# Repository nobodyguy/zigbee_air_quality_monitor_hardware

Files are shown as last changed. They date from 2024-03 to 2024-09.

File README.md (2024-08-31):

# Zigbee air quality monitor board
Opensource HA compatible air quality monitor with CO2, temperature and humidity measurements.

* KiCAD 8.X required 
* Includes nrf52840 module
* Includes SCD40/SCD41 module

## Firmware
https://github.com/nobodyguy/zigbee_air_quality_monitor_firmware

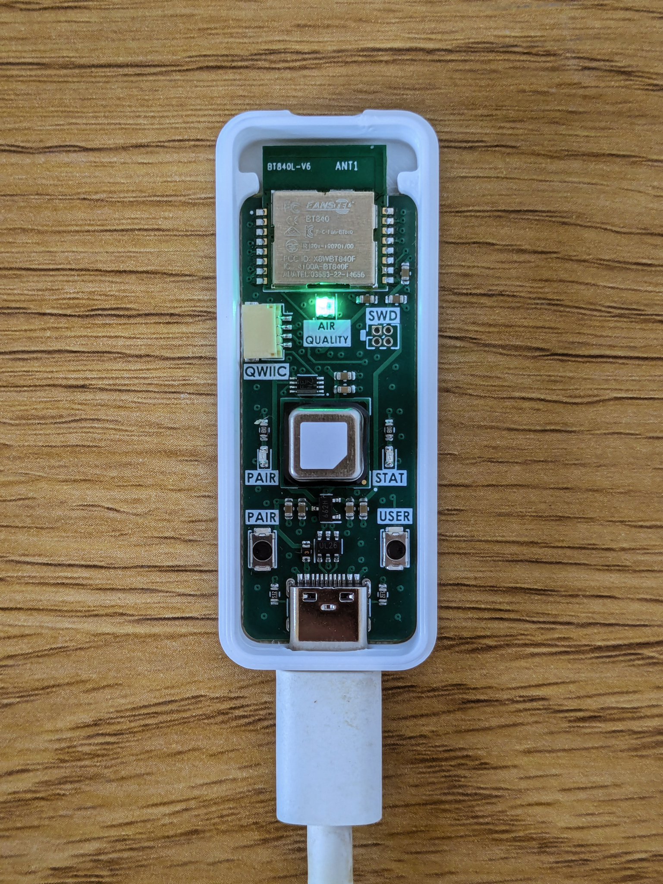
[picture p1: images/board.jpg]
Board


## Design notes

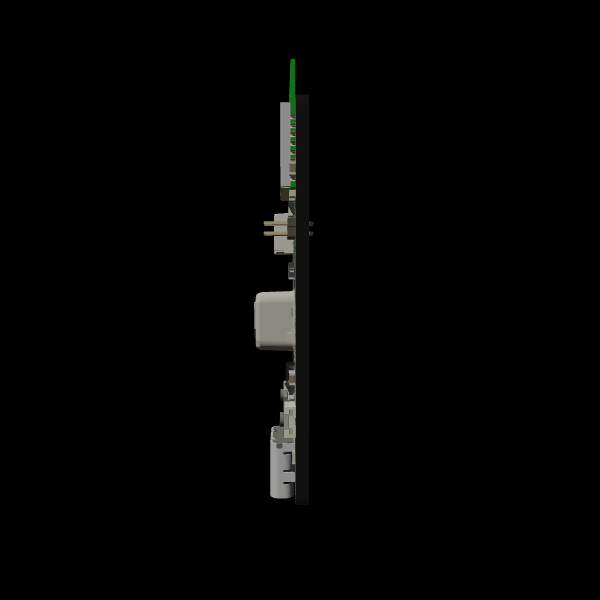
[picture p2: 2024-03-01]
images/pcb_animation.gif

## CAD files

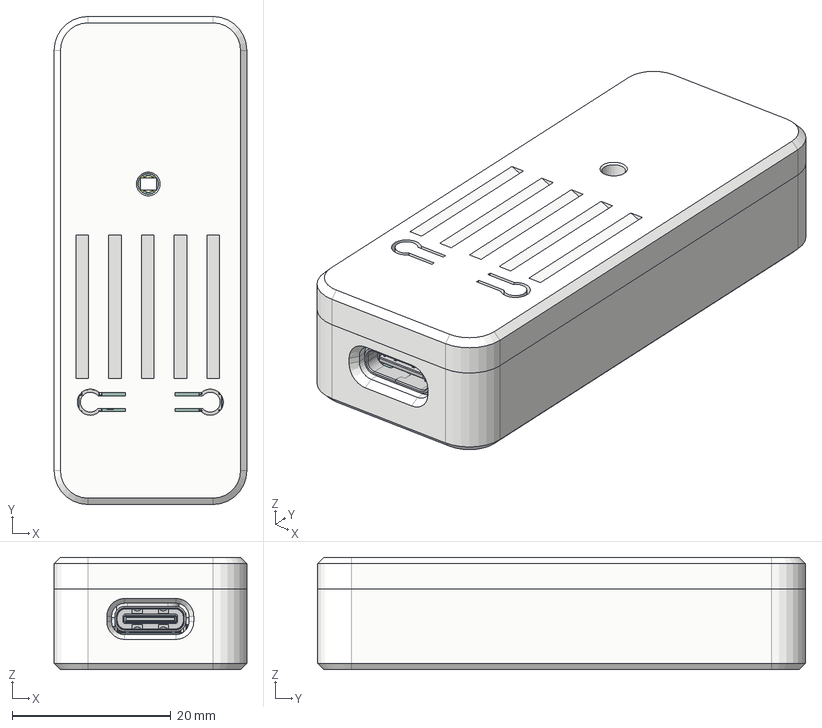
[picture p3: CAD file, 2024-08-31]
enclosure/zigbee_air_quality_monitor_case_v69.step
24.2 x 61.4 x 14.1 mm
R_0603_1608Metric x 4
C_0603_1608Metric x 11
zigbee_air_quality_monitor 1.5.1
149693-00_SCD4x_Datasheet
SOT_23_6
L_0603_1608Metric
SKRKAEE020 x 2
SOT_23
Fuse_0603_1608Metric
TYPE-C-31-M-12
LED_0603_1608Metric x 2
VSSOP_8_23x2mm_P05mm
PinHeader_2x02_P127mm_Vertical
WS2812B-2020
BT840
zigbee_air_quality_monitor PCB
TopCase
BottomCase

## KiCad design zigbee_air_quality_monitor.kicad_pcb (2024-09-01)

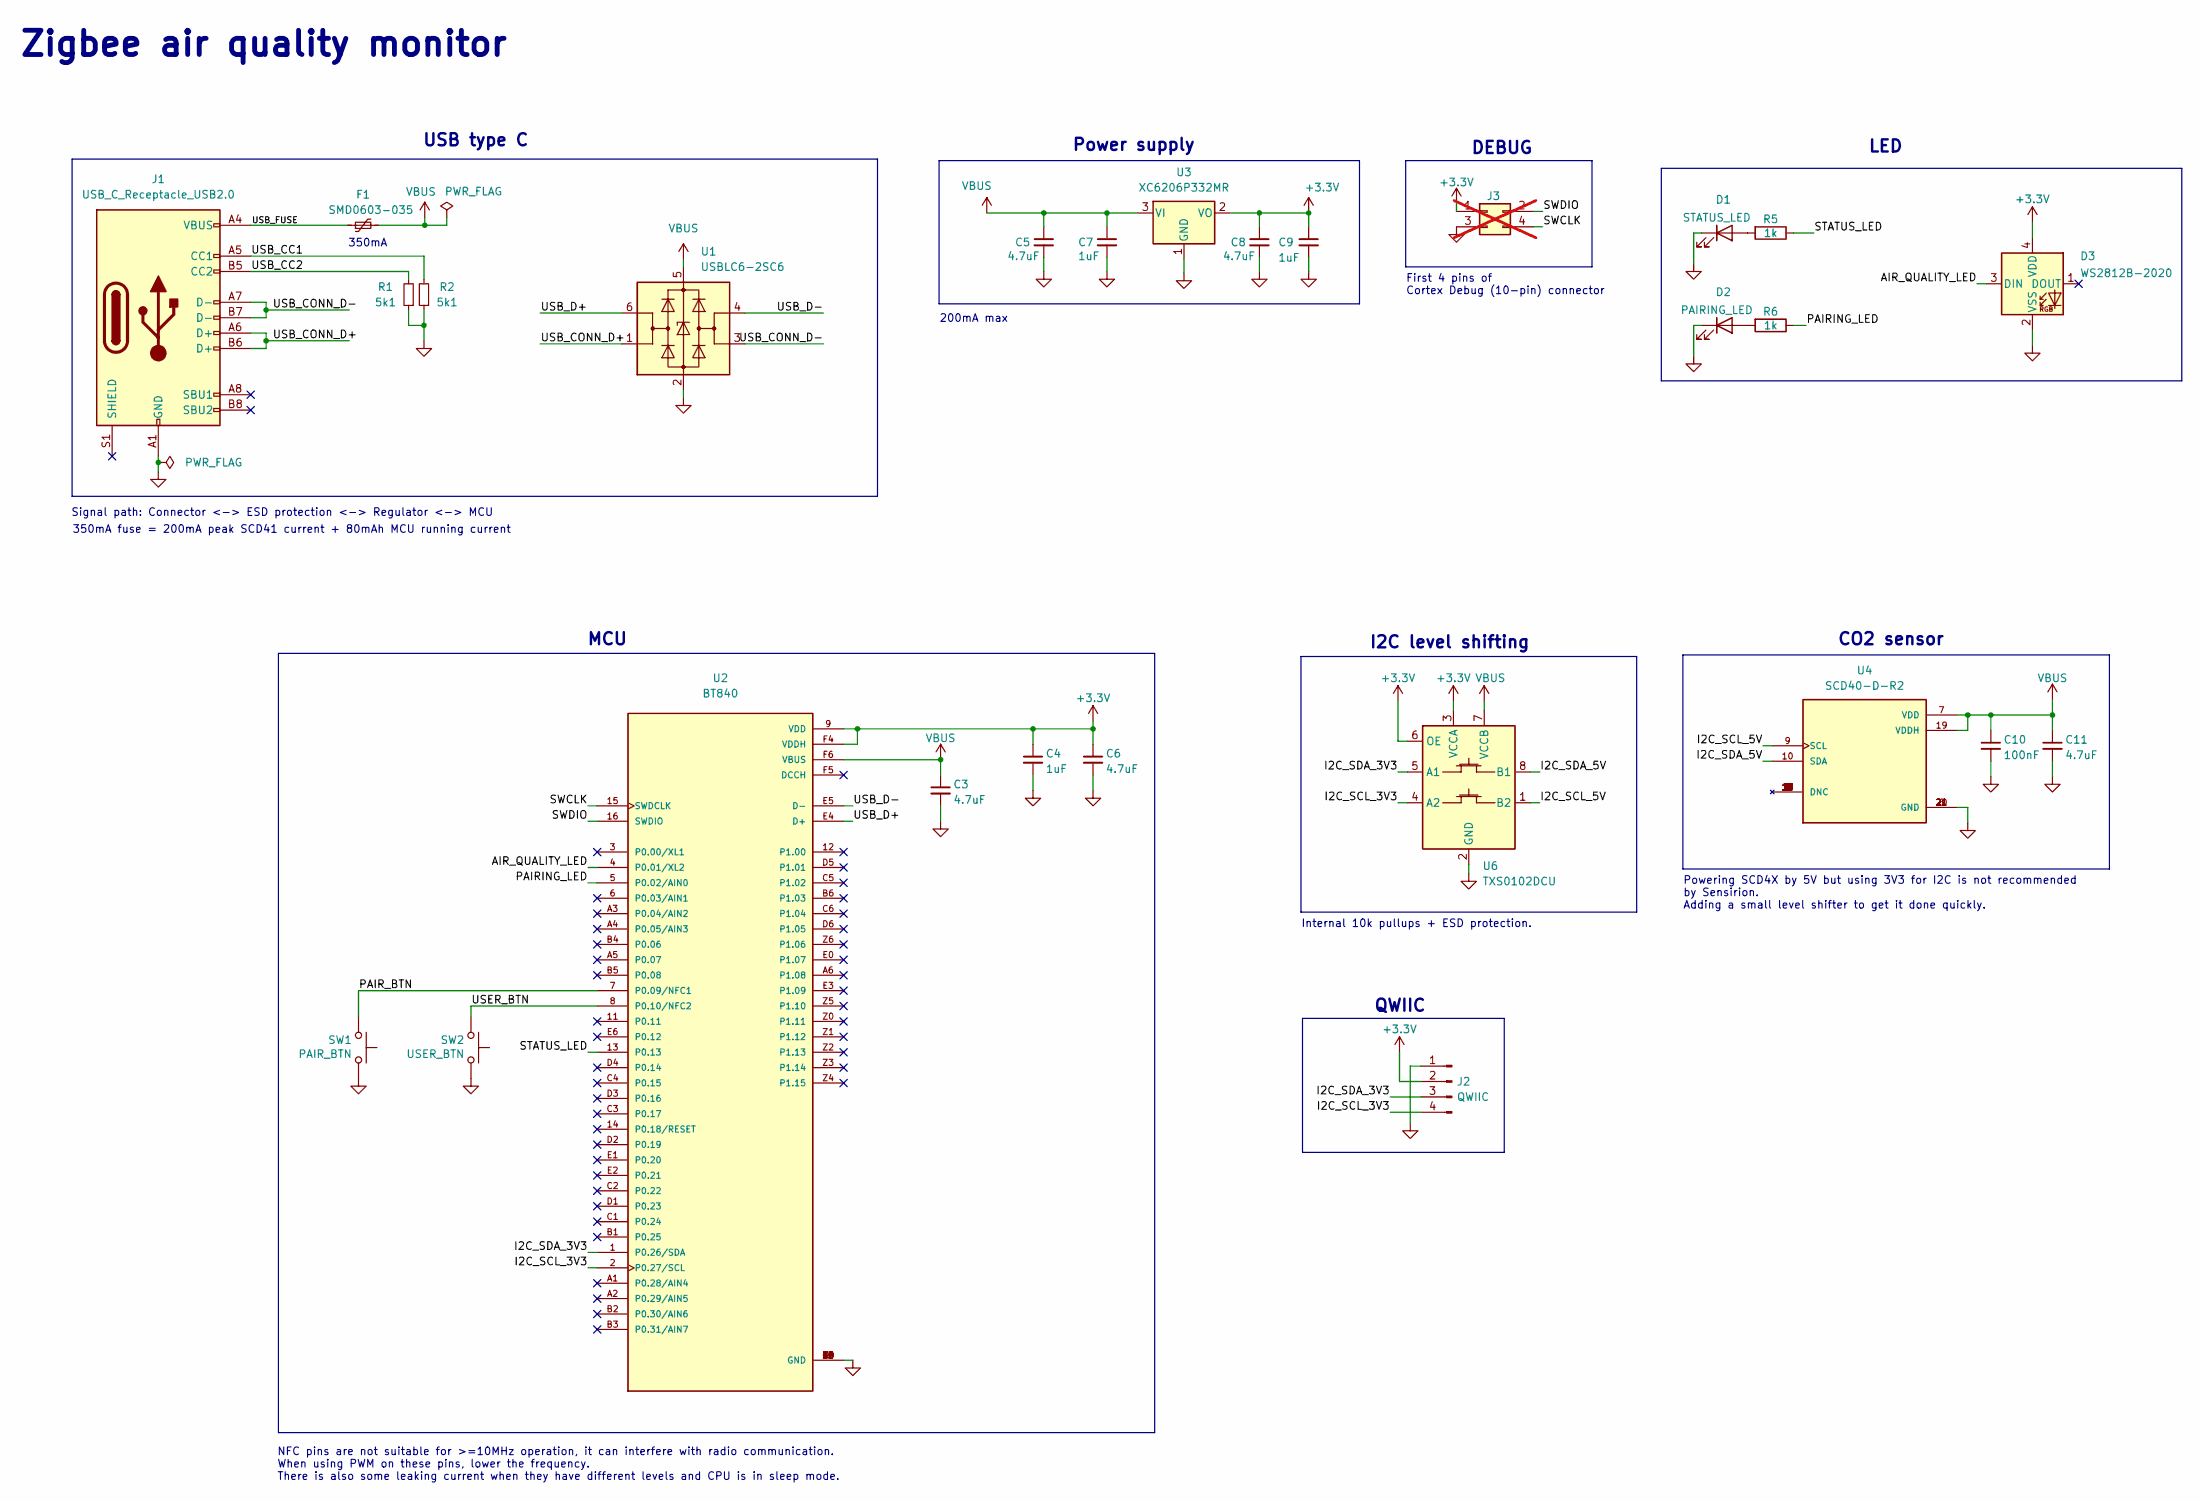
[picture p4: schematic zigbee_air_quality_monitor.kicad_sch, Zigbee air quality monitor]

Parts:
C3, C5, C6, C8, C11: 4.7uF; C_0603_1608Metric; LCSC Part C19666
C4, C7, C9: 1uF; C_0603_1608Metric; LCSC Part C15849
C10: 100nF; C_0603_1608Metric; LCSC Part C14663
D1: STATUS_LED; LED_0603_1608Metric; LCSC Part C965804
D2: PAIRING_LED; LED_0603_1608Metric; LCSC Part C965807
D3: WS2812B-2020; LED_WS2812B_PLCC4_5.0x5.0mm_P3.2mm; LCSC Part C965555
F1: SMD0603-035; Fuse_0603_1608Metric; LCSC Part C910818
J1: USB_C_Receptacle_USB2.0; USB_C_Receptacle_HRO_TYPE-C-31-M-12; LCSC Part C165948
J2: QWIIC; JST_SH_SM04B-SRSS-TB_1x04-1MP_P1.00mm_Horizontal; LCSC Part C9900058894
J3: Conn_02x02_Odd_Even; PinHeader_2x02_P1.27mm_Vertical; not fitted
R1, R2: 5k1; R_0603_1608Metric; LCSC Part C23186
R5, R6: 1k; R_0603_1608Metric; LCSC Part C21190
SW1: PAIR_BTN; SW_Push_SPST_NO_Alps_SKRK; LCSC Part C115357
SW2: USER_BTN; SW_Push_SPST_NO_Alps_SKRK; LCSC Part C115357
U1: USBLC6-2SC6; SOT-23-6; LCSC Part C2827654
U2: BT840; LCSC Part C5182373
U3: XC6206P332MR; SOT-23; LCSC Part C5446
U4: SCD40-D-R2; XDCR_SCD41-D-R2; PARTREV 1.2; LCSC Part C3659421
U6: TXS0102DCU; VSSOP-8_2.3x2mm_P0.5mm; LCSC Part C53434

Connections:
+3.3V: C4.1, C6.1, C8.1, C9.1, D3.4 (VDD), J2.2, J3.1, U2.9 (VDD), U2.F4 (VDDH), U3.2 (VO), U6.3 (VCCA), U6.6 (OE)
/AIR_QUALITY_LED: D3.3 (DIN), U2.4 (P0.01/XL2)
/I2C_SCL_3V3: J2.4, U2.2 (P0.27/SCL), U6.4 (A2)
/I2C_SCL_5V: U4.9 (SCL), U6.1 (B2)
/I2C_SDA_3V3: J2.3, U2.1 (P0.26/SDA), U6.5 (A1)
/I2C_SDA_5V: U4.10 (SDA), U6.8 (B1)
/PAIRING_LED: R6.1, U2.5 (P0.02/AIN0)
/PAIR_BTN: SW1.1, U2.7 (P0.09/NFC1)
/STATUS_LED: R5.1, U2.13 (P0.13)
/SWCLK: J3.4, U2.15 (SWDCLK)
/SWDIO: J3.2, U2.16 (SWDIO)
/USB_CC1: J1.A5 (CC1), R2.2
/USB_CC2: J1.B5 (CC2), R1.2
/USB_CONN_D+: J1.A6 (D+), J1.B6 (D+), U1.1 (I/O1)
/USB_CONN_D-: J1.A7 (D-), J1.B7 (D-), U1.3 (I/O2)
/USB_D+: U1.6 (I/O1), U2.E4 (D+)
/USB_D-: U1.4 (I/O2), U2.E5 (D-)
/USB_FUSE: F1.1, J1.A4 (VBUS), J1.A9 (VBUS), J1.B4 (VBUS), J1.B9 (VBUS)
/USER_BTN: SW2.1, U2.8 (P0.10/NFC2)
GND: C3.2, C4.2, C5.2, C6.2, C7.2, C8.2, C9.2, C10.2, C11.2, D1.1 (K), D2.1 (K), D3.2 (VSS), J1.A1 (GND), J1.A12 (GND), J1.B1 (GND), J1.B12 (GND), J2.1, J3.3, R1.1, R2.1, SW1.2, SW2.2, U1.2 (GND), U2.10 (GND), U2.A0 (GND), U2.B0 (GND), U2.C0 (GND), U2.D0 (GND), U2.F0 (GND), U2.F1 (GND), U2.F2 (GND), U2.F3 (GND), U3.1 (GND), U4.6 (GND), U4.20 (GND), U4.21 (GND), U6.2 (GND)
unnamed: D1.2 (A), R5.2
unnamed: D2.2 (A), R6.2
VBUS: C3.1, C5.1, C7.1, C10.1, C11.1, F1.2, U1.5 (VBUS), U2.F6 (VBUS), U3.3 (VI), U4.7 (VDD), U4.19 (VDDH), U6.7 (VCCB)

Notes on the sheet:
Internal 10k pullups + ESD protection.
DEBUG
LED
MCU
350mA
Power supply
200mA max
NFC pins are not suitable for >=10MHz operation, it can interfere with radio communication. When using PWM on these pins, lower the frequency. There is also some leaking current when they have different levels and CPU is in sleep mode.
Powering SCD4X by 5V but using 3V3 for I2C is not recommended by Sensirion. Adding a small level shifter to get it done quickly.
USB type C
CO2 sensor
First 4 pins of Cortex Debug (10-pin) connector
Signal path: Connector <-> ESD protection <-> Regulator <-> MCU
I2C level shifting
350mA fuse = 200mA peak SCD41 current + 80mAh MCU running current
Zigbee air quality monitor
QWIIC

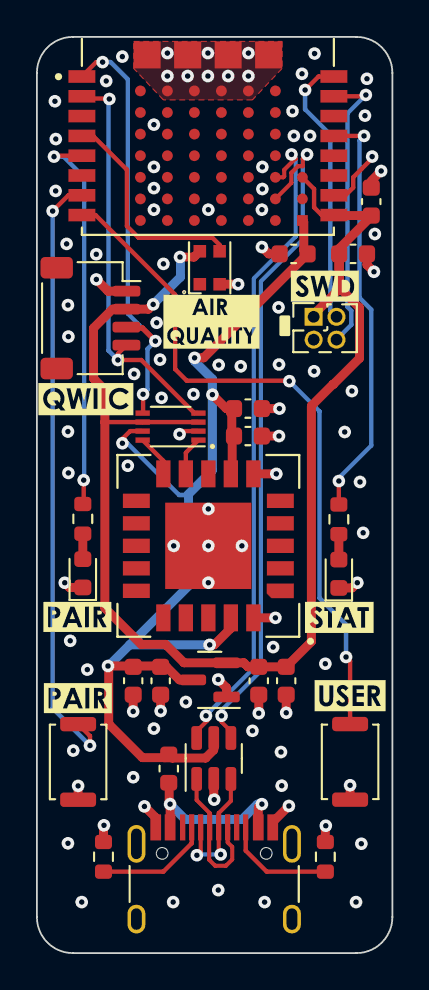
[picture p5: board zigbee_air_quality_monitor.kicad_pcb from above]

Board: 4 copper layers, 19.8 x 50.9 mm, 35 parts (1 on the bottom side), 23 nets.

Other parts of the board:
G1: LOGO
kibuzzard-63D9ACF8: G***; kibuzzard-63D9ACF8
kibuzzard-63D64B8B, kibuzzard-63D64B8B#2: G***; kibuzzard-63D64B8B
kibuzzard-63D64B66: G***; kibuzzard-63D64B66
kibuzzard-63D6450F: G***; kibuzzard-63D6450F
kibuzzard-63D64107: G***; kibuzzard-63D64107
kibuzzard-63D64589: G***; footprint

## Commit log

2023-01-20 Zigbee module, PN and jtag schematics
    [zigbee_air_quality_monitor.kicad_pcb, zigbee_air_quality_monitor.kicad_sch]
2023-01-29 Finished schematics, added 3D models
    [zigbee_air_quality_monitor.kicad_pcb, zigbee_air_quality_monitor.kicad_sch]
2023-02-04 Rough part placement
    [zigbee_air_quality_monitor.kicad_pcb, zigbee_air_quality_monitor.kicad_sch]
2024-02-25 Routing WIP
    [zigbee_air_quality_monitor.kicad_pcb, zigbee_air_quality_monitor.kicad_sch]
2024-02-25 CI test
    [zigbee_air_quality_monitor.kicad_pcb]
2024-02-26 USB routing WIP
    [zigbee_air_quality_monitor.kicad_pcb]
2024-02-26 All parts routed
    [zigbee_air_quality_monitor.kicad_pcb, zigbee_air_quality_monitor.kicad_sch]
2024-02-27 Added 300mA LDO
    [AP7343D-33FS4-7B.STEP]
2024-02-27 Added level translator for SCD40
    [zigbee_air_quality_monitor.kicad_pcb, zigbee_air_quality_monitor.kicad_sch]
2024-02-28 Added round corners to PCB
    [zigbee_air_quality_monitor.kicad_pcb, zigbee_air_quality_monitor.kicad_sch]
2024-02-28 Added inner GND planes, backside silkscreen label
    [zigbee_air_quality_monitor.kicad_pcb]
2024-02-28 Routing done, via stitching done
    [zigbee_air_quality_monitor.kicad_pcb, zigbee_air_quality_monitor.kicad_sch]
2024-02-28 Fixed silkscreen logo designator to make KiBot happy
    [zigbee_air_quality_monitor.kicad_pcb]
2024-02-29 Fixed QWIIC connector footprint and model
    [SM04B-SRSS-TB.STEP, zigbee_air_quality_monitor.kicad_pcb, zigbee_air_quality_monitor.kicad_sch]
2024-03-01 Added PCB render animation
2024-03-02 Changed supply voltage for WS2812-2020 LED to 5V
    [zigbee_air_quality_monitor.kicad_pcb, zigbee_air_quality_monitor.kicad_sch]
2024-03-02 LED exact name, SCD40 exact name
    [zigbee_air_quality_monitor.kicad_sch]
2024-03-02 Fixed clipped silkscreen, ERC+DRC warnings
    [zigbee_air_quality_monitor.kicad_pcb]
2024-03-02 Fixed SCD footprint name
    [zigbee_air_quality_monitor.kicad_pcb]
2024-03-08 Symbol and footprint project libs cleanup
    [AP7343D-33FS4-7B.STEP, SM04B-SRSS-TB.STEP, zigbee_air_quality_monitor.kicad_pcb]
2024-08-01 rev2
    Fixed RGB LED footprint, removed problematic button caps, cleaning
    [zigbee_air_quality_monitor.kicad_pcb, zigbee_air_quality_monitor.kicad_sch]
2024-08-01 Manufacturing fixes
    [zigbee_air_quality_monitor.kicad_pcb, zigbee_air_quality_monitor.kicad_sch]
2024-08-31 Added enclosure
    [zigbee_air_quality_monitor_case_v69.step]
2024-09-01 Buttons aligned
    [zigbee_air_quality_monitor.kicad_pcb]
